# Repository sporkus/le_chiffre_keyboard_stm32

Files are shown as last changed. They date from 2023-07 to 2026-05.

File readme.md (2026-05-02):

# Le Chiffre Keyboard - STM32 version
-----------

Open sourced PCB originally design by tominabox1 updated to STM32 MCU.

## Design goals
* Drop-in replacement to existing cases
* MCU: STM32F072CBT6 (128Kb flash, built-in DFU bootloader) to allow more firmware features
* MX hotswap, Alps support
* Optional 36 key support

## Firmware
* [QMK and vial source](./firmware)
* [zmk config](https://github.com/petejohanson/le-chiffre-stm32-zmk-config)
* [pre-compiled vial](./firmware/le_chiffre_32_vial.bin)

To flash initially using dfu-util or qmk toolbox, plug in the board or push the reset button while DFU button is held down.

## Fabrication
* verified production files can be found [here](./pcb_production)
* pcb dimensions: 84.96x227.34mm
* SK6812 mini 3535 has placement marker on "Data In" pin. Don't confuse it with sk6812-HS mini or sk6812 mini-E.

## Misc
#### 3D assembly preview
* [online viewer](https://3dviewer.net/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)
* [step assembly](./documentation/stm32_hotswap_chiffre-3D.step)

#### PCB renders
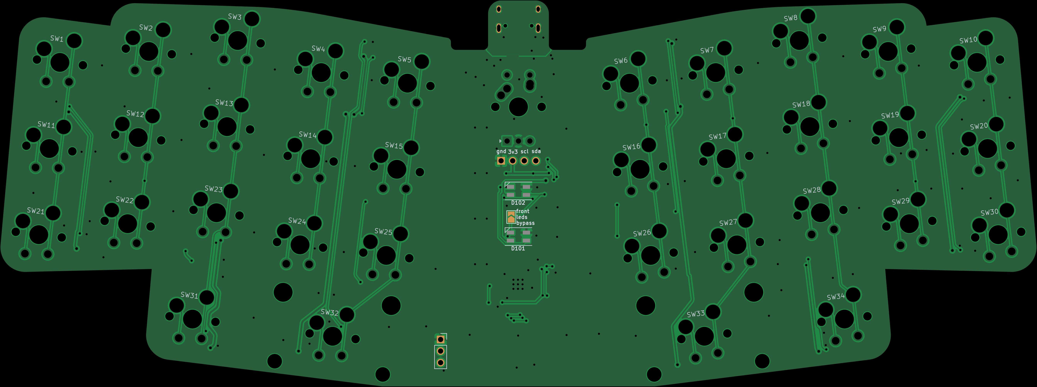
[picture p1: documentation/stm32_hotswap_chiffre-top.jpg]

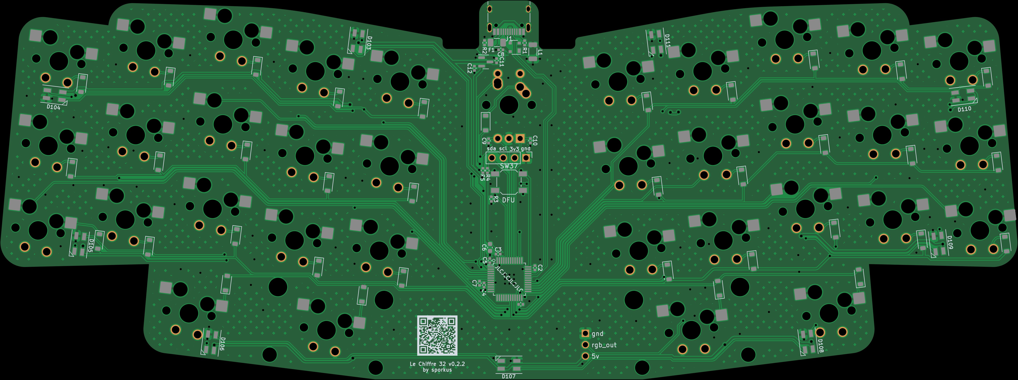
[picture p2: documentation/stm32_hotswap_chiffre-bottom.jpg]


#### BoM
[interactive BoM](./documentation/stm32_hotswap_chiffre-ibom.html)

#### Schematic
[Schematic pdf](./documentation/stm32_hotswap_chiffre-schematic.pdf)

#### Case
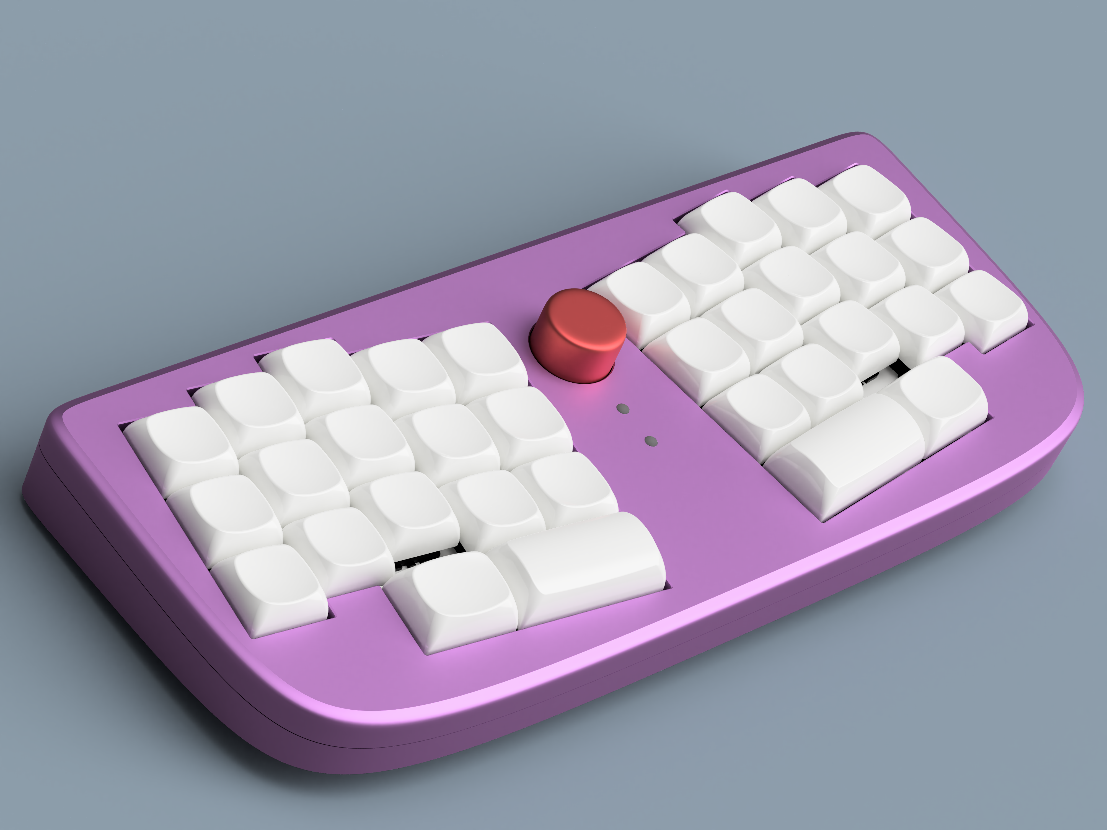
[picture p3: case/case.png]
3d printable case


## Credits
tominabox1 for the [original design](https://github.com/tominabox1/Le-Chiffre-Keyboard)

## Changelog
* v0.3.0: add optional 36 key support
* v0.2.2: change center switch to soldered instead of hotswap. Group buy.
* v0.2.1: added front led bypass jumper
* v0.2.0: improved protection circuit
* v0.1: working initial prototypes

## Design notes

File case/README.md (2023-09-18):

# 3d printable case
---

- 4-degree top mount case.
- Two versions of case top provided in stl:
    - 19mm knob + 2.5 diameter lightpipes
    - plain top with no cutouts

### Hardware
- 15x: m2 x 3mm x 3mm heatset insert
- 15x: m2 x 6mm or 8mm screws (depend on o-rings used)
- 0 - 23x: 2mm ID x 2mm height x 6mm diameter orings
- 2x: 2.5mm diameter x 11mm lightpipes (can be cut down from longer)
- 4x: [SKUF](https://github.com/Zambumon/SKUF)


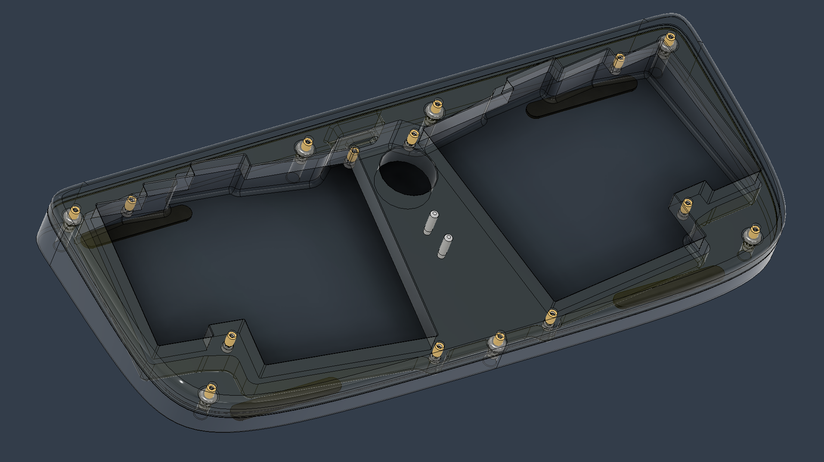
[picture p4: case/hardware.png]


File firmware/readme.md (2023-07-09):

# Le Chiffre 32

32-bit version of the Le Chiffre originally designed by tominabox1

* Keyboard Maintainer: [sporkus](https://github.com/sporkus)
* Hardware Supported: APM32F072
* Hardware Availability: [](https://github.com/sporkus/le_chiffre_keyboard_stm32)

Make example for this keyboard (after setting up your build environment):

    qmk compile -kb sporkus/le_chiffre_stm32 -km default

Flashing example for this keyboard:

    qmk flash -kb sporkus/le_chiffre_stm32 -km default

See the [build environment setup](https://docs.qmk.fm/#/getting_started_build_tools) and the [make instructions](https://docs.qmk.fm/#/getting_started_make_guide) for more information. Brand new to QMK? Start with our [Complete Newbs Guide](https://docs.qmk.fm/#/newbs).

## Bootloader

Enter the DFU bootloader in 3 ways:

* **Physical DFU button**: hold the button while powering up the keyboard
* **Keycode in layout**: Press the key mapped to `QK_BOOT` if it is available

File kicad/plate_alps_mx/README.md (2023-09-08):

# Mixed Alps/MX plate

All cutouts are for Alps except MX cutouts in the 2u keys

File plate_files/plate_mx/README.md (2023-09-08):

# MX Plate

* one piece version based on https://github.com/tominabox1/Le-Chiffre-Keyboard/tree/master/KiCad/Le%20Chiffre%20v2/LeChiffre_Plate

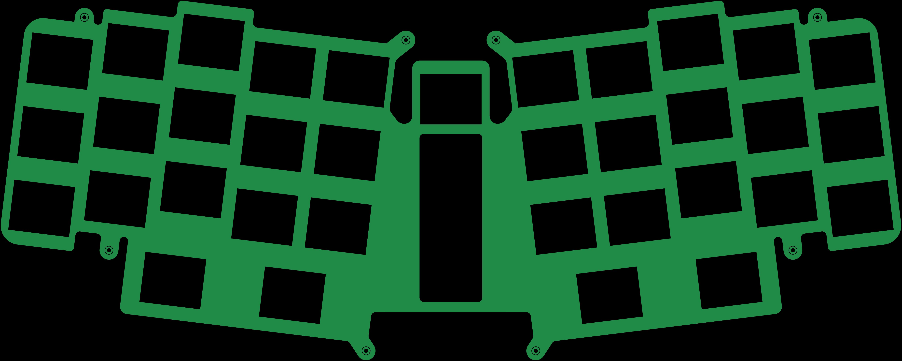
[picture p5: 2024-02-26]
plate_files/plate_alps/plate_alps-top.jpg

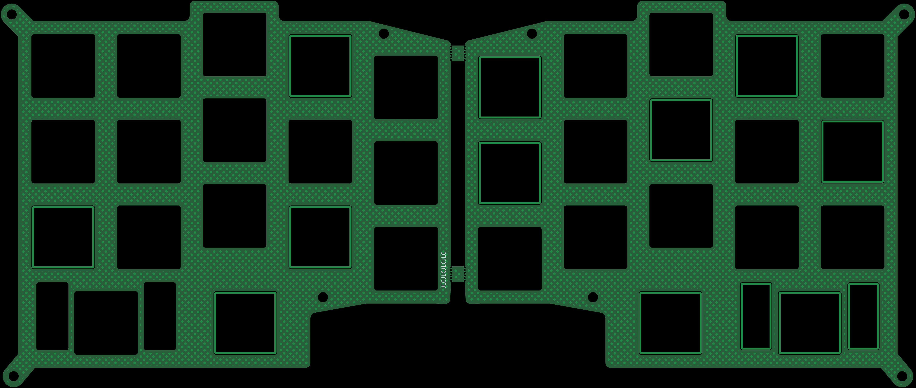
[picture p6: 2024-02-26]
plate_files/plate_mx/LeChiffre_Plate-top.jpg

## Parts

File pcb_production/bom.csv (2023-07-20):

Designator | Footprint | Quantity | Value | LCSC Part #
C1, C10, C2, C3, C4, C5, C7, C8, C9 | 0402 | 9 | 100nF | C307331
C11, C12 | 0402 | 2 | 1uF | C52923
C6 | 0603 | 1 | 10uF
D1, D10, D11, D12, D13, D14, D15, D16, D17, D18, D19, D2, D20, D21, D22, D23, D24, D25, D26, D27, D28, D29, D3, D30, D31, D32, D33, D34, D35, D4, D5, D6, D7, D8, D9 | D_SOD-123 | 35 | 1N4148W
D101, D102, D103, D104, D105, D106, D107, D108, D109, D110, D111 | LED_SK6812MINI_PLCC4_3.5x3.5mm_P1.75mm | 11 | SK6812MINI
F1 | 1206 | 1 | ASMD1206-150 | C135341
J1 | USB_C_Receptacle_HRO_TYPE-C-31-M-12 | 1 | USB_C_Receptacle_USB2.0
J101 | PinSocket_1x03_P2.54mm_Vertical | 1 | Conn_01x03_Female
JP2 | SolderJumper-2_P1.3mm_Open_TrianglePad1.0x1.5mm | 1 | Jumper_2_Open
L1 | 1206 | 1 | 60R@100MHz | C33600
R1, R2 | 0402 | 2 | 5.1k
R3 | 0402 | 1 | 10k
R4, R5 | 0402 | 2 | 4.7k
SW1, SW10, SW11, SW12, SW13, SW14, SW15, SW16, SW17, SW18, SW19, SW2, SW20, SW21, SW22, SW23, SW24, SW25, SW26, SW27, SW28, SW29, SW3, SW30, SW4, SW5, SW6, SW7, SW8, SW9 | MX-Hotswap-Alps-1U | 30 | SW_Push
SW31, SW34 | MX-Hotswap-Alps-1.25U | 2 | SW_Push
SW32, SW33 | MX-Hotswap-Alps-2U | 2 | SW_Push
SW35 | MX-Alps-Hybrid-1U | 1 | SW_Push
SW37 | SW_SPST_SKQG_WithoutStem | 1 | SKQGABE010 | C115351
U1 | LQFP-48_7x7mm_P0.5mm | 1 | STM32F072CBT6
U2 | SOT-143 | 1 | PRTR5V0U2X | C2827688
U3 | SOT-23 | 1 | XC6206PxxxMR-Regulator_Linear | C5446

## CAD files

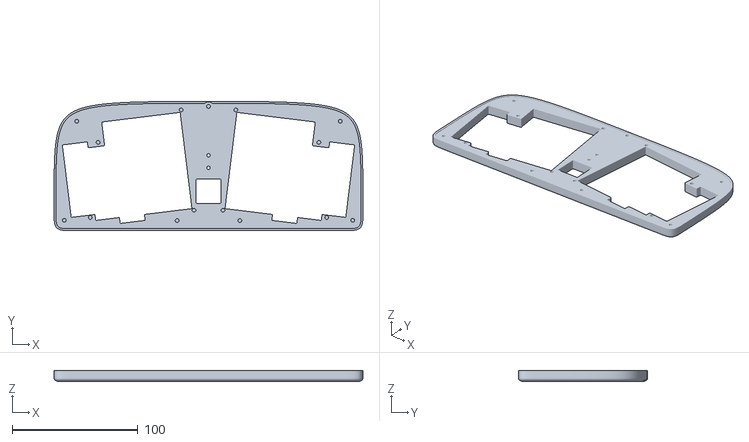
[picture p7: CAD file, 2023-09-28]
case/top_switch_cutout.stl
246.0 x 102.9 x 8.65

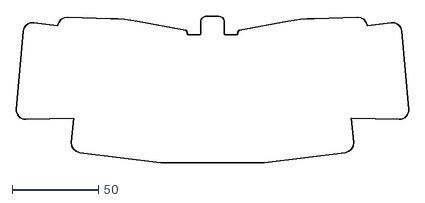
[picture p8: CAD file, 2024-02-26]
documentation/34key/stm32_hotswap_chiffre-Edge_Cuts.dxf
227.6 x 84.9

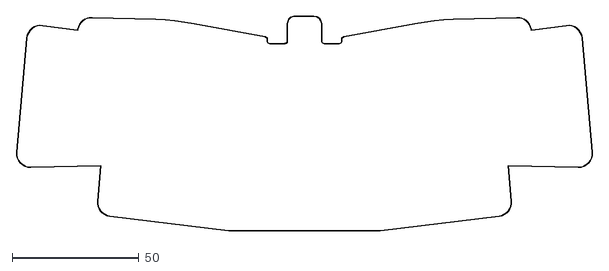
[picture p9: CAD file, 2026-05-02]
documentation/36key/stm32_chiffre_36keys-Edge_Cuts.dxf
227.6 x 84.9

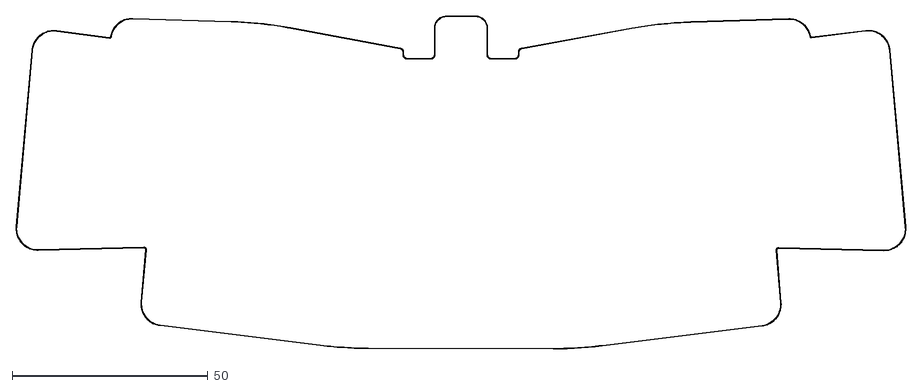
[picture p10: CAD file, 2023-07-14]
kicad/pcb/stm32_hotswap_chiffre-Edge_Cuts.dxf
227.4 x 85.0

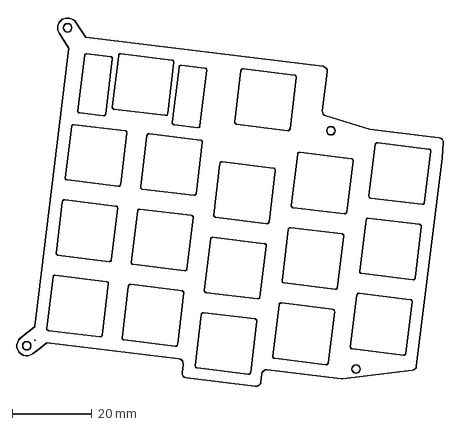
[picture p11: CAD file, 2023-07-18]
kicad/plate/Plate 5.14.32 PM.dxf
107.2 x 92.9 mm

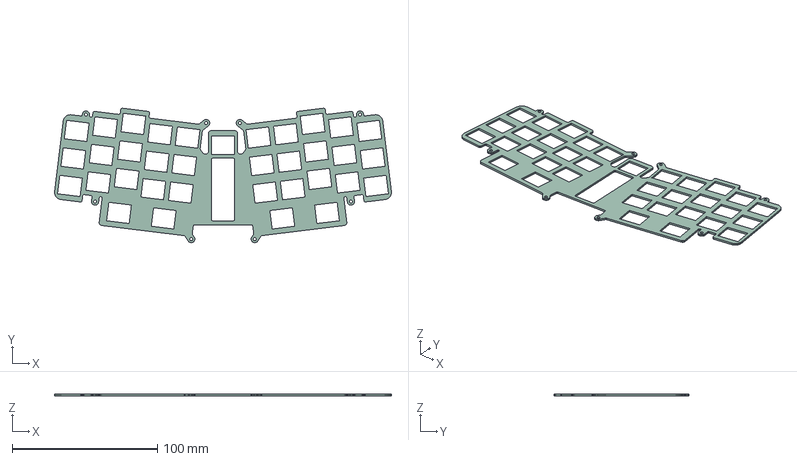
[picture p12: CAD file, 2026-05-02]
plate_files/plate_alps/plate_alps-3D.step
231.6 x 92.5 x 1.20 mm

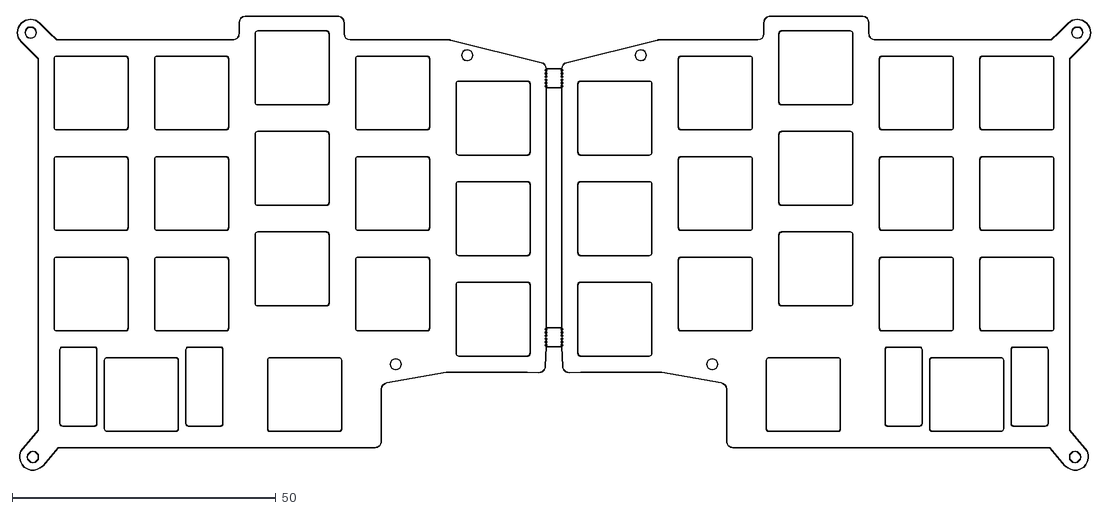
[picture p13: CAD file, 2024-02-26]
plate_files/plate_mx/LeChiffre_Plate-Edge_Cuts.dxf
203.9 x 86.2

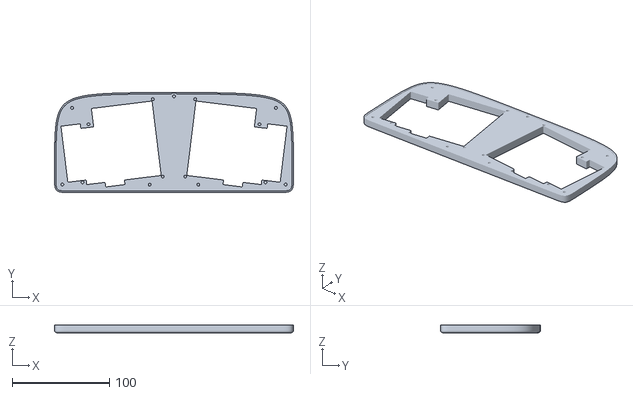
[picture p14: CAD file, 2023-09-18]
case/top_plain.stl
246.0 x 102.9 x 8.65

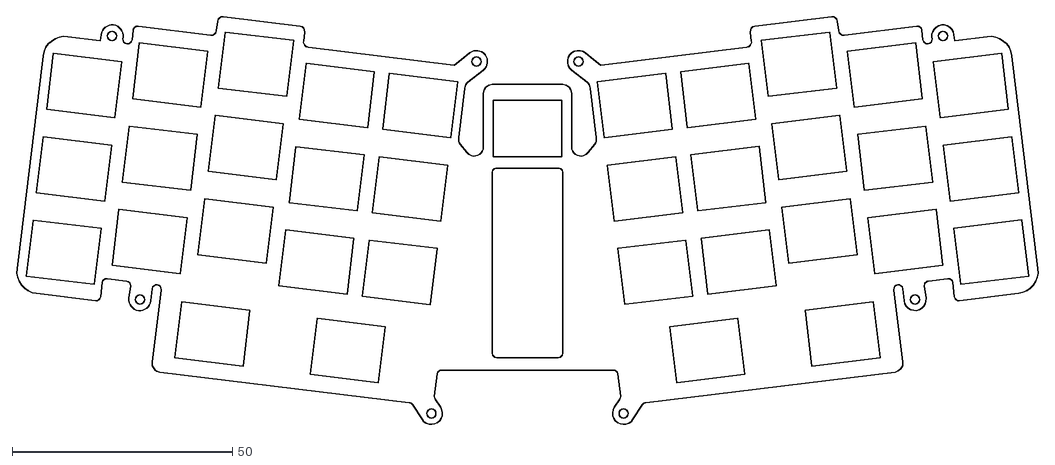
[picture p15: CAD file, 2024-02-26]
plate_files/plate_alps/plate_alps-Edge_Cuts.dxf
231.9 x 92.6

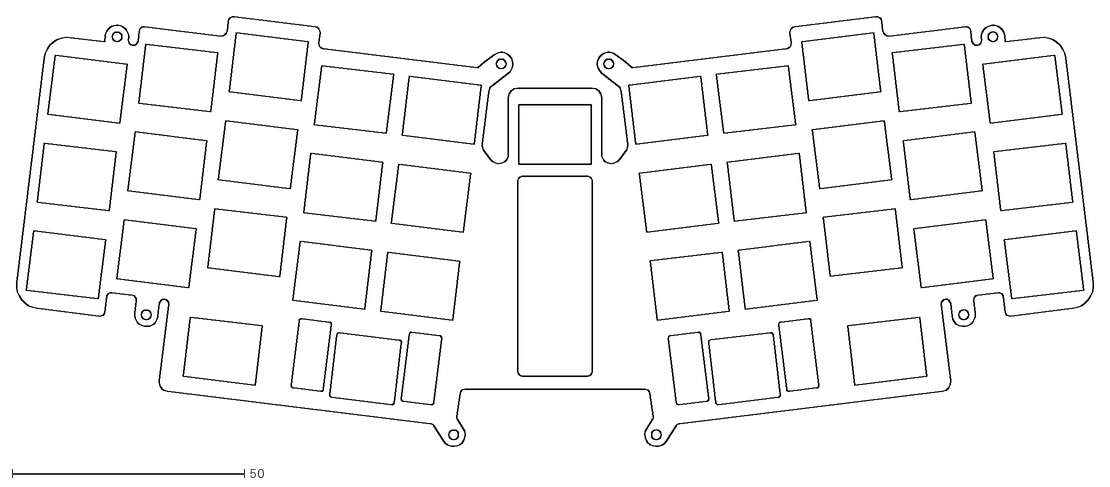
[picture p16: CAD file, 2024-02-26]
plate_files/plate_alps_mx/plate_alps_mx-Edge_Cuts.dxf
231.9 x 92.6

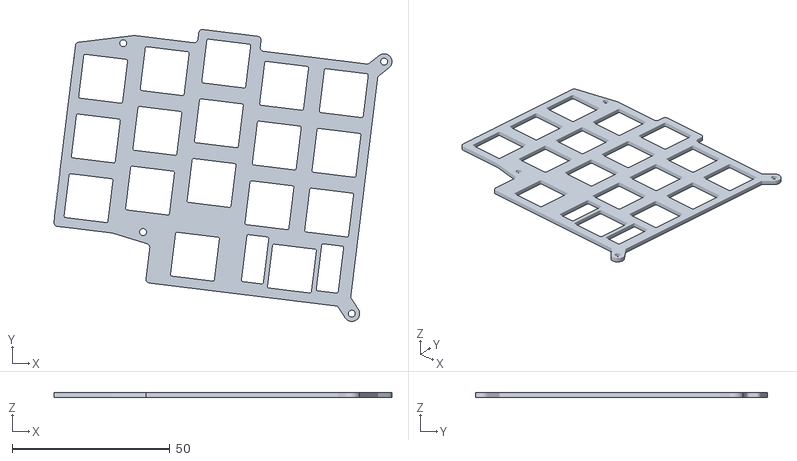
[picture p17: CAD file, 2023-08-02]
case/plate.stl
107.1 x 92.5 x 1.60

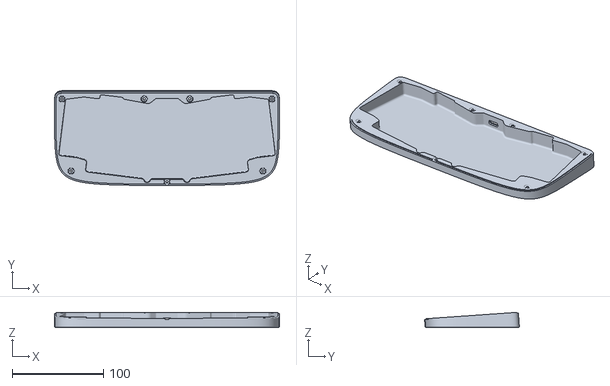
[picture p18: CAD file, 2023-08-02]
case/bottom.stl
246.0 x 103.7 x 16.7

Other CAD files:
plate_files/plate_alps_mx/plate_alps_mx-3D.step
case/top.stl

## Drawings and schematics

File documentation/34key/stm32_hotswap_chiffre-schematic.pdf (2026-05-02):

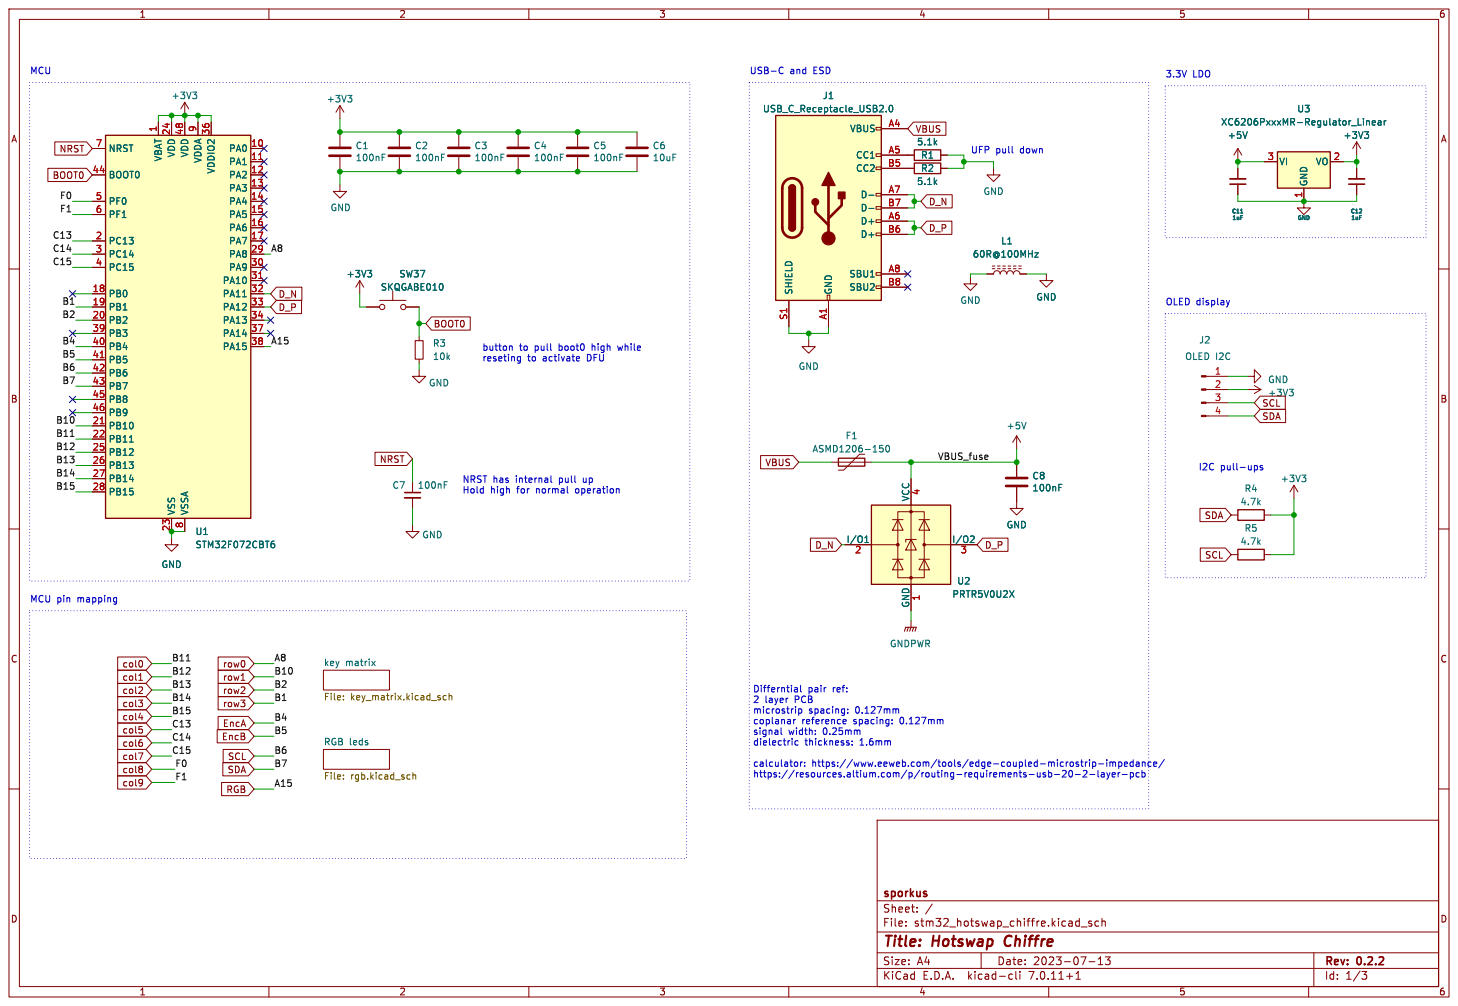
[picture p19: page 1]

3.3V LDO MCU pin mapping

1 PA0 10 PA1 11 PA2 12 PA3 13 PA4 14 PA5 15 PA6 16 PA7 17 PB0 18 PB1 19 PC13 2 PB2 20 PB10 21 PB11 22 VSS 23 VDD 24 PB12 25 PB13 26 PB14 27 PB15 28 PA8 29 PC14 3 PA9 30 PA10 31 PA11 32 PA12 33 PA13 34 VDDIO2 36 PA14 37 PA15 38 PB3 39 PC15 4 PB4 40 PB5 41 PB6 42 PB7 43 BOOT0 44 PB8 45 PB9 46 VDD 48 PF0 5 PF1 6 NRST 7 VSSA

button to pull boot0 high while

File: stm32_hotswap_chiffre.kicad_sch Sheet: / sporkus RGB leds File: rgb.kicad_sch

https://resources.altium.com/p/routing-requirements-usb-20-2-layer-pcb

Id: 1/3 Title: Hotswap Chiffre

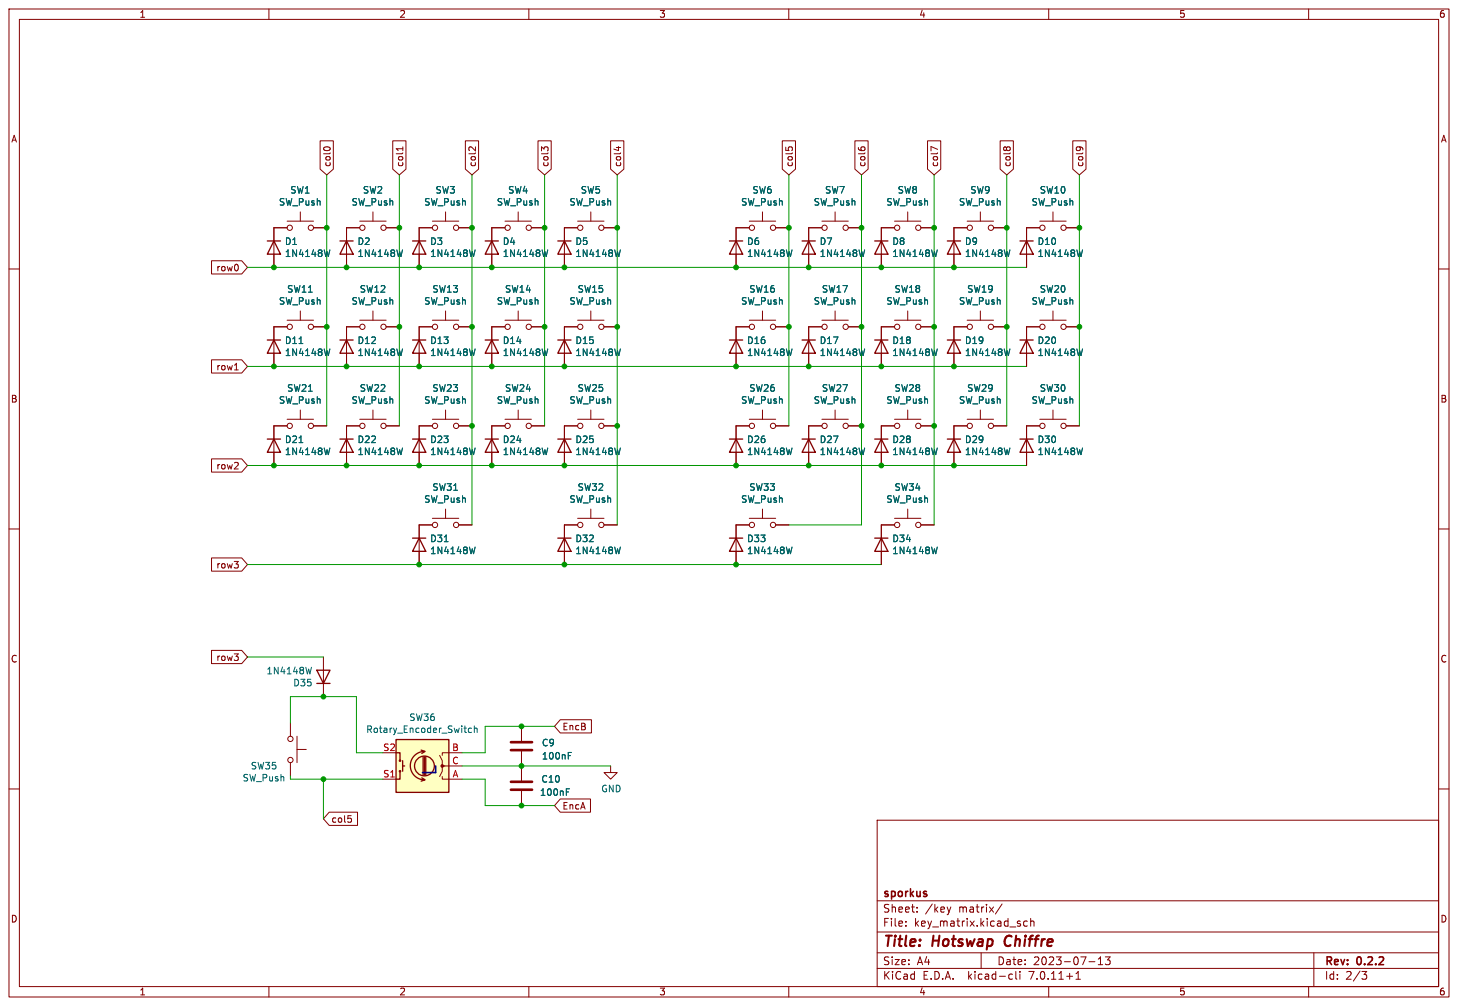
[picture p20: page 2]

File: key_matrix.kicad_sch Sheet: /key matrix/ sporkus SW33 SW_Push D25

Id: 2/3 Title: Hotswap Chiffre

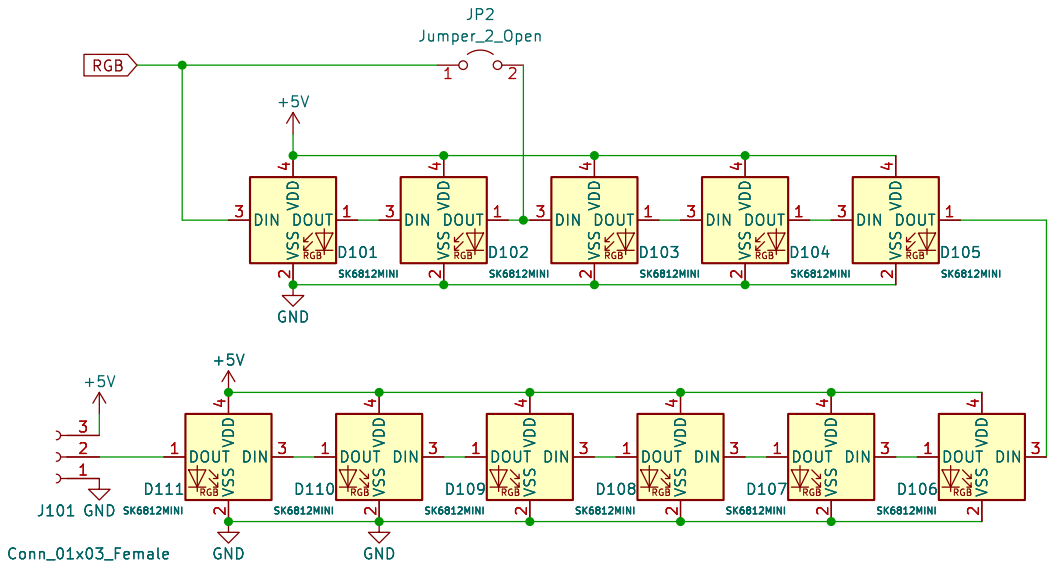
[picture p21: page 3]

Id: 3/3 Title: Hotswap Chiffre

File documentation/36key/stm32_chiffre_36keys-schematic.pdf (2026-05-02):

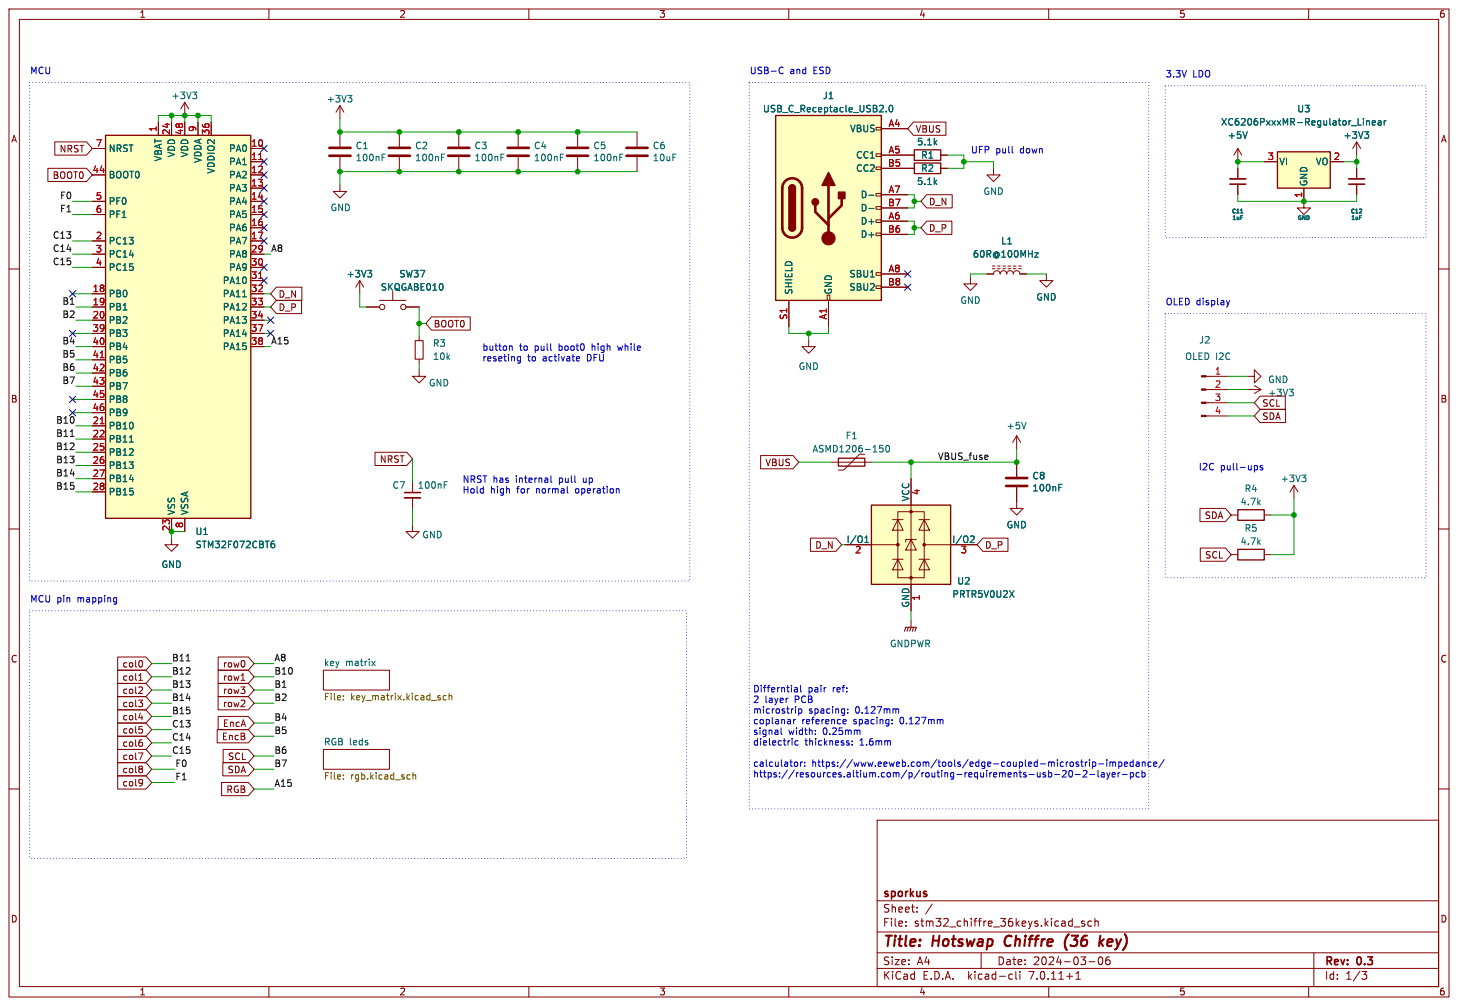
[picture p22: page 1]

1 PA0 10 PA1 11 PA2 12 PA3 13 PA4 14 PA5 15 PA6 16 PA7 17 PB0 18 PB1 19 PC13 2 PB2 20 PB10 21 PB11 22 VSS 23 VDD 24 PB12 25 PB13 26 PB14 27 PB15 28 PA8 29 PC14 3 PA9 30 PA10 31 PA11 32 PA12 33 PA13 34 VDDIO2 36 PA14 37 PA15 38 PB3 39 PC15 4 PB4 40 PB5 41 PB6 42 PB7 43 BOOT0 44 PB8 45 PB9 46 VDD 48 PF0 5 PF1 6 NRST 7 VSSA

button to pull boot0 high while

Id: 1/3 Title: Hotswap Chiffre (36 key) File: stm32_chiffre_36keys.kicad_sch Sheet: / sporkus RGB leds File: rgb.kicad_sch

https://resources.altium.com/p/routing-requirements-usb-20-2-layer-pcb

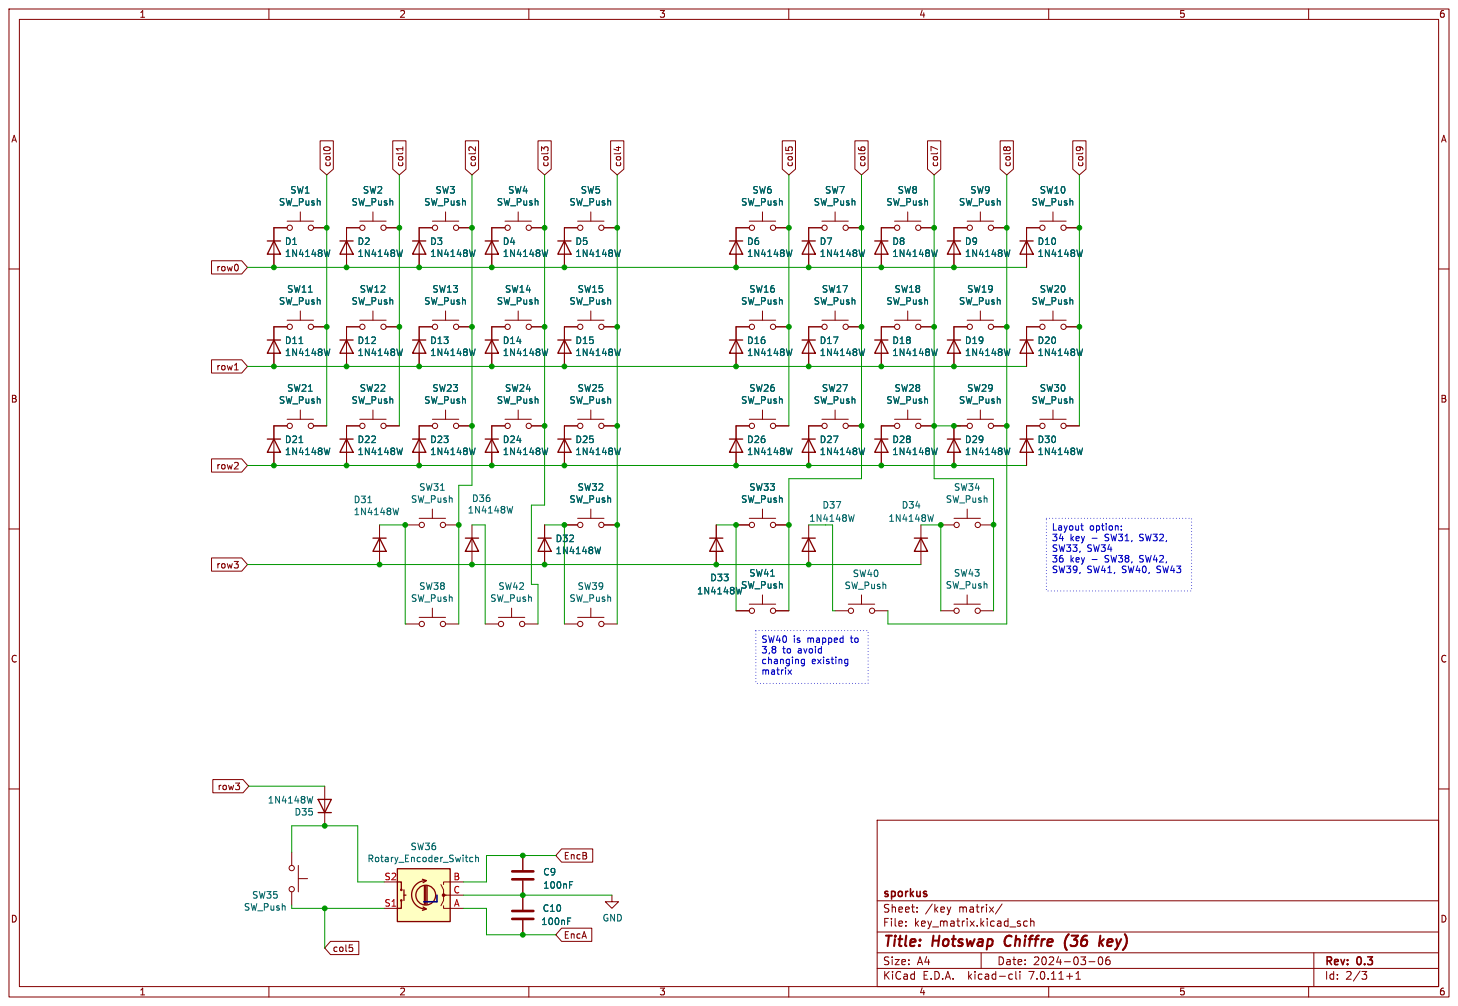
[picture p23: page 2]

Id: 2/3 Title: Hotswap Chiffre (36 key) File: key_matrix.kicad_sch Sheet: /key matrix/ sporkus SW32 SW_Push D5


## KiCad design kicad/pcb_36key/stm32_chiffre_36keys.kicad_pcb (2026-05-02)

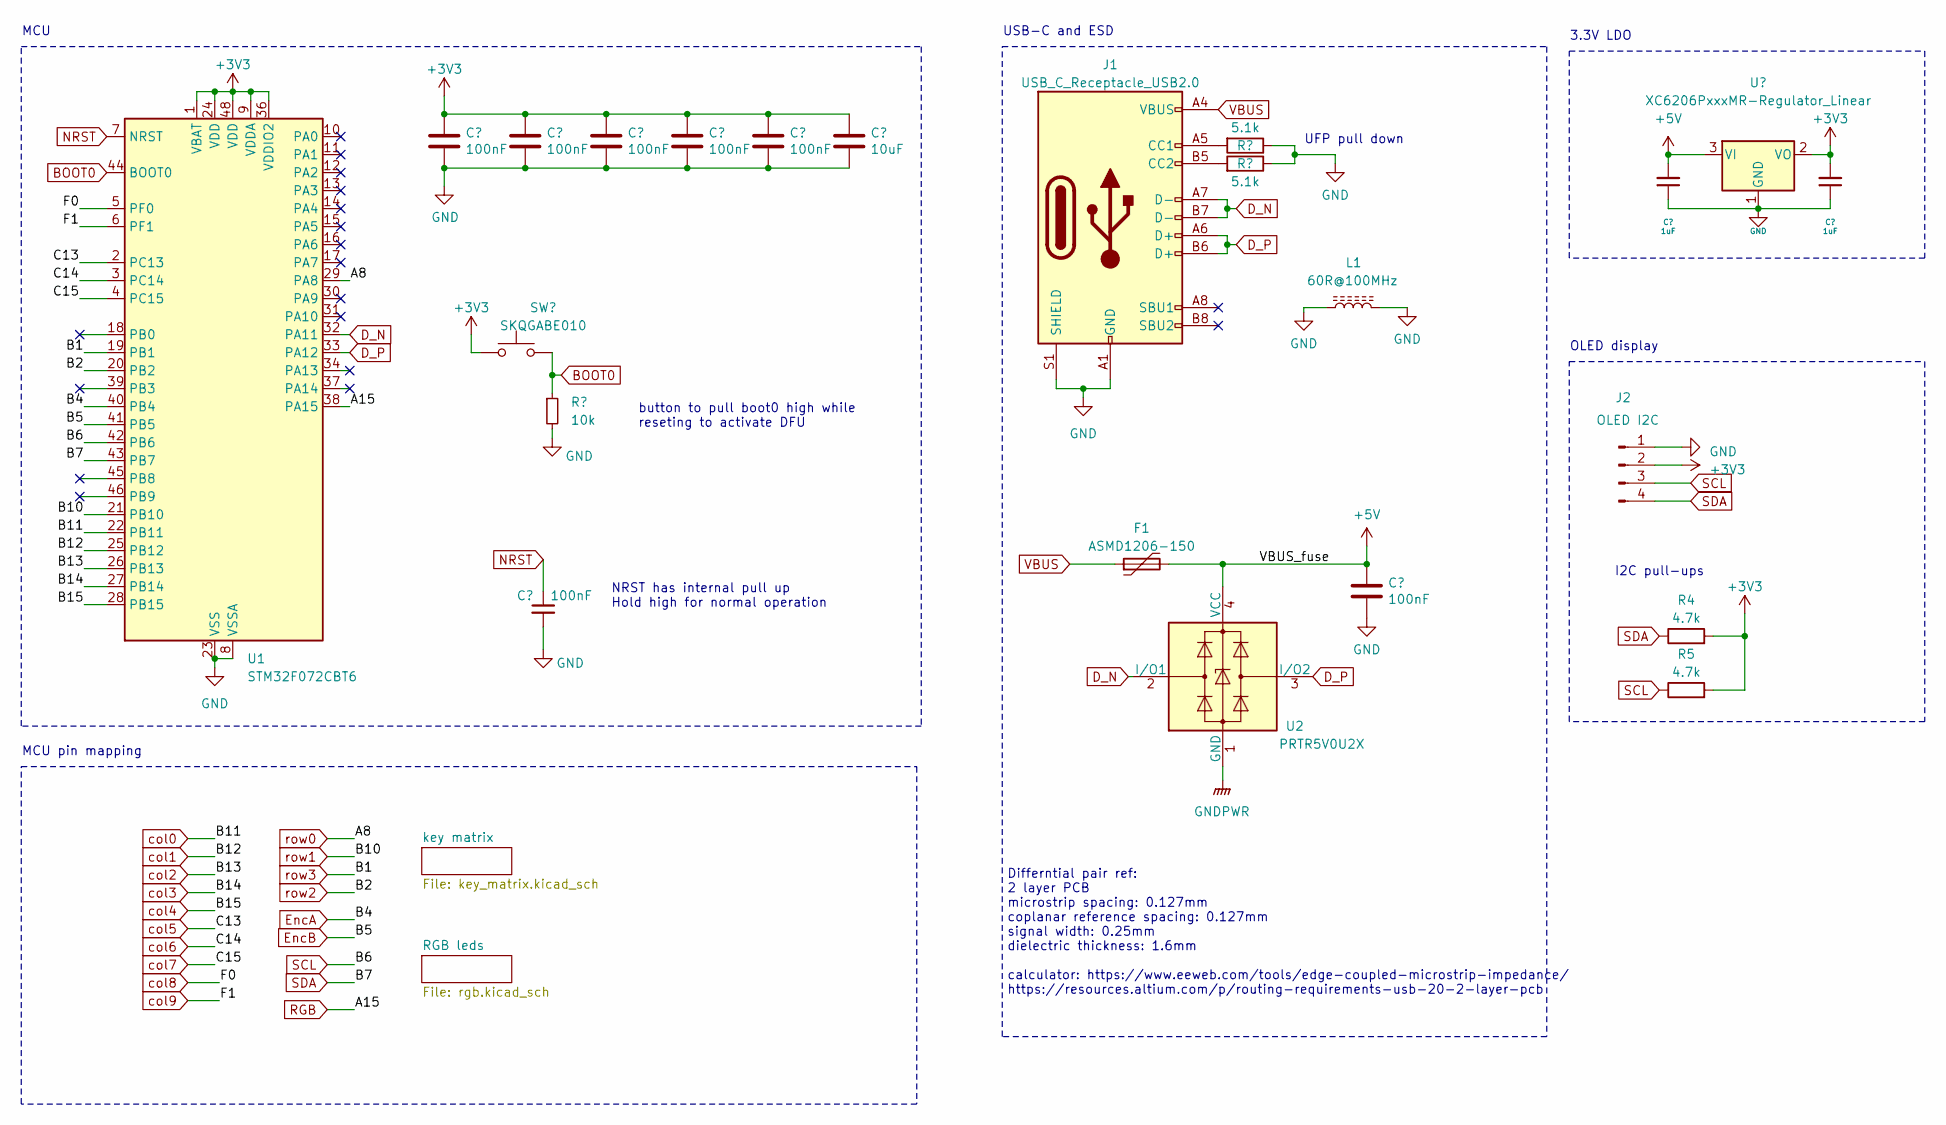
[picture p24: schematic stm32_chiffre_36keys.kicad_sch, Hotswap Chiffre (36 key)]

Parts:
C1, C2, C3, C4, C5, C7, C8: 100nF; C_0402_1005Metric; LCSC C307331
C6: 10uF; C_0603_1608Metric
C11, C12: 1uF; C_0402_1005Metric; LCSC C52923
F1: ASMD1206-150; Fuse_1206_3216Metric; LCSC C135341
J1: USB_C_Receptacle_USB2.0; USB_C_Receptacle_HRO_TYPE-C-31-M-12; JlcRotOffset 180
J2: OLED I2C; PinHeader_1x04_P2.54mm_Vertical
L1: 60R@100MHz; L_1206_3216Metric; Manufacturer Part No MLB3216-600P4A(f); LCSC C33600
R1, R2: 5.1k; R_0402_1005Metric
R3: 10k; R_0402_1005Metric
R4, R5: 4.7k; R_0402_1005Metric
SW37: SKQGABE010; SW_SPST_SKQG_WithoutStem; LCSC C115351
U1: STM32F072CBT6; LQFP-48_7x7mm_P0.5mm; JlcRotOffset 90
U2: PRTR5V0U2X; SOT-143; LCSC C2827688
U3: XC6206PxxxMR-Regulator_Linear; SOT-23; LCSC C5446

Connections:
+3V3: C1.1, C2.1, C3.1, C4.1, C5.1, C6.1, C12.2, J2.2, R4.2, R5.2, SW37.1, U1.1 (VBAT), U1.9 (VDDA), U1.24 (VDD), U1.36 (VDDIO2), U1.48 (VDD), U3.2 (VO)
+5V: C8.1, C11.2, F1.2, U2.4 (VCC), U3.3 (VI); also elsewhere on the board
BOOT0: R3.1, SW37.2, U1.44 (BOOT0)
D_N: J1.A7 (D-), J1.B7 (D-), U1.32 (PA11), U2.2 (I/O1)
D_P: J1.A6 (D+), J1.B6 (D+), U1.33 (PA12), U2.3 (I/O2)
EncA: U1.40 (PB4); also elsewhere on the board
EncB: U1.41 (PB5); also elsewhere on the board
GND: C1.2, C2.2, C3.2, C4.2, C5.2, C6.2, C7.2, C8.2, C11.1, C12.1, J1.A1 (GND), J1.A12 (GND), J1.B1 (GND), J1.B12 (GND), J1.S1 (SHIELD), J2.1, L1.1, L1.2, R1.1, R2.1, R3.2, U1.8 (VSSA), U1.23 (VSS), U1.35 (VSS), U1.47 (VSS), U3.1 (GND); also elsewhere on the board
GNDPWR: U2.1 (GND)
NRST: C7.1, U1.7 (NRST)
unnamed: J1.A5 (CC1), R1.2
unnamed: J1.B5 (CC2), R2.2
RGB: U1.38 (PA15); also elsewhere on the board
SCL: J2.3, R5.1, U1.42 (PB6)
SDA: J2.4, R4.1, U1.43 (PB7)
VBUS: F1.1, J1.A4 (VBUS), J1.A9 (VBUS), J1.B4 (VBUS), J1.B9 (VBUS)
col0: U1.22 (PB11); also elsewhere on the board
col1: U1.25 (PB12); also elsewhere on the board
col2: U1.26 (PB13); also elsewhere on the board
col3: U1.27 (PB14); also elsewhere on the board
col4: U1.28 (PB15); also elsewhere on the board
col5: U1.2 (PC13); also elsewhere on the board
col6: U1.3 (PC14); also elsewhere on the board
col7: U1.4 (PC15); also elsewhere on the board
col8: U1.5 (PF0); also elsewhere on the board
col9: U1.6 (PF1); also elsewhere on the board
row0: U1.29 (PA8); also elsewhere on the board
row1: U1.21 (PB10); also elsewhere on the board
row2: U1.20 (PB2); also elsewhere on the board
row3: U1.19 (PB1); also elsewhere on the board

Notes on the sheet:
button to pull boot0 high while reseting to activate DFU
I2C pull-ups
UFP pull down
MCU pin mapping
MCU
3.3V LDO
USB-C and ESD
OLED display
NRST has internal pull up Hold high for normal operation
Differntial pair ref: 2 layer PCB microstrip spacing: 0.127mm coplanar reference spacing: 0.127mm signal width: 0.25mm dielectric thickness: 1.6mm calculator: https://www.eeweb.com/tools/edge-coupled-microstrip-impedance/ https://resources.altium.com/p/routing-requirements-usb-20-2-layer-pcb

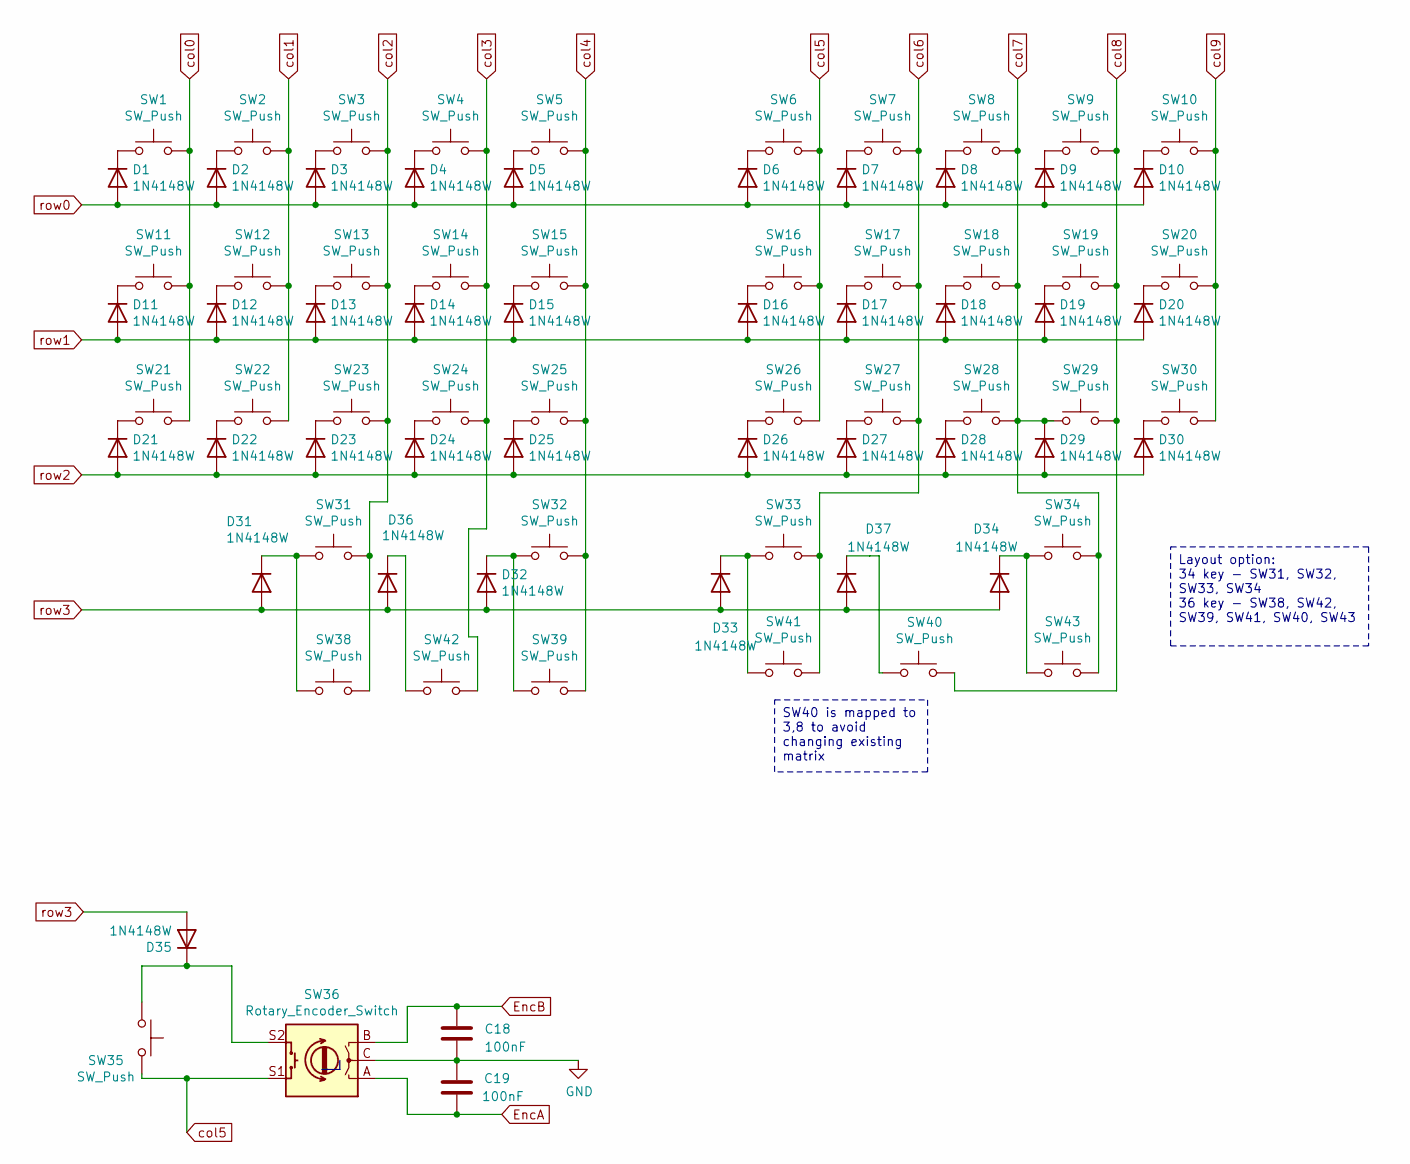
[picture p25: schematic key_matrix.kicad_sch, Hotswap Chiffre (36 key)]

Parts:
C18, C19: 100nF; C_0402_1005Metric; LCSC C307331
D1, D2, D3, D4, D5, D11, D12, D13, D14, D15, D21, D22, D23, D24, D25, D31, D32, D36: 1N4148W; D_SOD-123; JlcRotOffset 14
D6, D7, D8, D9, D10, D16, D17, D18, D19, D20, D26, D27, D28, D29, D30, D33, D34, D37: 1N4148W; D_SOD-123; JlcRotOffset -14
D35: 1N4148W; D_SOD-123; JlcRotOffset 0
SW1, SW2, SW3, SW4, SW5, SW6, SW7, SW8, SW9, SW10, SW11, SW12, SW13, SW14, SW15, SW16, SW17, SW18, SW19, SW20, SW21, SW22, SW23, SW24, SW25, SW26, SW27, SW28, SW29, SW30, SW38, SW40, SW41, SW42: SW_Push; MX-Hotswap-Alps-1U
SW31, SW34, SW39, SW43: SW_Push; MX-Hotswap-Alps-1.25U
SW32, SW33: SW_Push; MX-Hotswap-Alps-2U
SW35: SW_Push; MX-Alps-Hybrid-1U
SW36: Rotary_Encoder_Switch; RotaryEncoder_EC11_no_mp

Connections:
EncA: SW36.A; also elsewhere on the board
EncB: SW36.B; also elsewhere on the board
GND: SW36.C; also elsewhere on the board
unnamed: D1.1 (K), SW1.1
unnamed: D2.1 (K), SW2.1
unnamed: D3.1 (K), SW3.1
unnamed: D4.1 (K), SW4.1
unnamed: D5.1 (K), SW5.1
unnamed: D6.1 (K), SW6.1
unnamed: D7.1 (K), SW7.1
unnamed: D8.1 (K), SW8.1
unnamed: D9.1 (K), SW9.1
unnamed: D10.1 (K), SW10.1
unnamed: D11.1 (K), SW11.1
unnamed: D12.1 (K), SW12.1
unnamed: D13.1 (K), SW13.1
unnamed: D14.1 (K), SW14.1
unnamed: D15.1 (K), SW15.1
unnamed: D16.1 (K), SW16.1
unnamed: D17.1 (K), SW17.1
unnamed: D18.1 (K), SW18.1
unnamed: D19.1 (K), SW19.1
unnamed: D20.1 (K), SW20.1
unnamed: D21.1 (K), SW21.1
unnamed: D22.1 (K), SW22.1
unnamed: D23.1 (K), SW23.1
unnamed: D24.1 (K), SW24.1
unnamed: D25.1 (K), SW25.1
unnamed: D26.1 (K), SW26.1
unnamed: D27.1 (K), SW27.1
unnamed: D28.1 (K), SW28.1
unnamed: D30.1 (K), SW30.1
unnamed: D31.1 (K), SW31.1, SW38.2
unnamed: D32.1 (K), SW32.1, SW39.2
unnamed: D33.1 (K), SW33.1, SW41.2
unnamed: D34.1 (K), SW34.2, SW43.1
unnamed: D35.1 (K), SW35.1, SW36.S2
unnamed: D36.1 (K), SW42.1
unnamed: D37.1 (K), SW40.1
col0: SW1.2, SW11.2, SW21.2; also elsewhere on the board
col1: SW2.2, SW12.2, SW22.2; also elsewhere on the board
col2: SW3.2, SW13.2, SW23.2, SW31.2, SW38.1; also elsewhere on the board
col3: SW4.2, SW14.2, SW24.2, SW42.2; also elsewhere on the board
col4: SW5.2, SW15.2, SW25.2, SW32.2, SW39.1; also elsewhere on the board
col5: SW6.2, SW16.2, SW26.2, SW35.2, SW36.S1; also elsewhere on the board
col6: SW7.2, SW17.2, SW27.2, SW33.2, SW41.1; also elsewhere on the board
col7: D29.1 (K), SW8.2, SW18.2, SW28.2, SW29.1, SW34.1, SW43.2; also elsewhere on the board
col8: SW9.2, SW19.2, SW29.2, SW40.2; also elsewhere on the board
col9: SW10.2, SW20.2, SW30.2; also elsewhere on the board
row0: D1.2 (A), D2.2 (A), D3.2 (A), D4.2 (A), D5.2 (A), D6.2 (A), D7.2 (A), D8.2 (A), D9.2 (A), D10.2 (A); also elsewhere on the board
row1: D11.2 (A), D12.2 (A), D13.2 (A), D14.2 (A), D15.2 (A), D16.2 (A), D17.2 (A), D18.2 (A), D19.2 (A), D20.2 (A); also elsewhere on the board
row2: D21.2 (A), D22.2 (A), D23.2 (A), D24.2 (A), D25.2 (A), D26.2 (A), D27.2 (A), D28.2 (A), D29.2 (A), D30.2 (A); also elsewhere on the board
row3: D31.2 (A), D32.2 (A), D33.2 (A), D34.2 (A), D35.2 (A), D36.2 (A), D37.2 (A); also elsewhere on the board

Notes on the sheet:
SW40 is mapped to 3,8 to avoid changing existing matrix
Layout option: 34 key - SW31, SW32, SW33, SW34 36 key - SW38, SW42, SW39, SW41, SW40, SW43

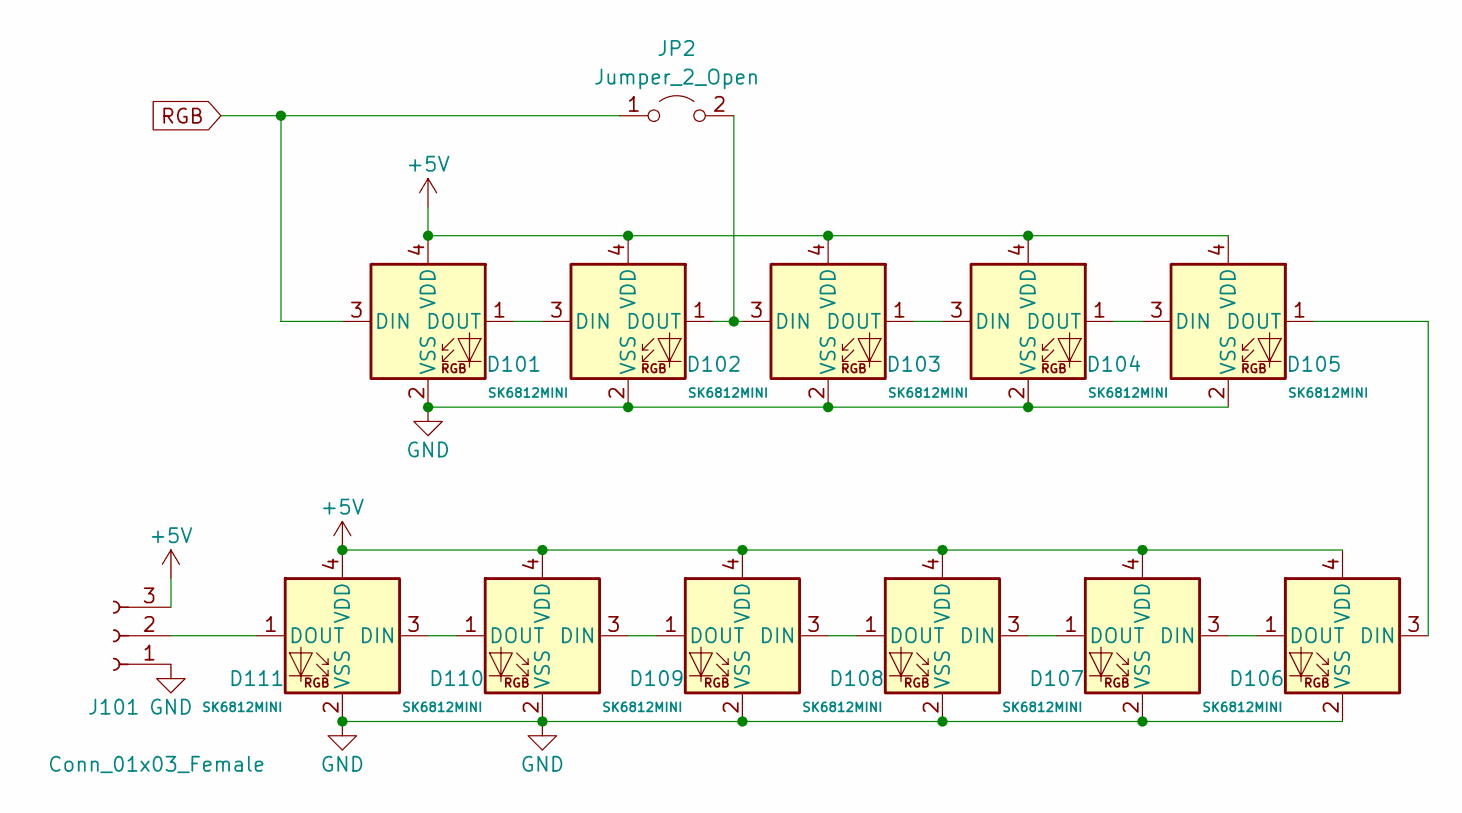
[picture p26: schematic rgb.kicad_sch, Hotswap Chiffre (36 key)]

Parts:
D101, D102: SK6812MINI; LED_SK6812MINI_PLCC4_3.5x3.5mm_P1.75mm
D103, D105, D106: SK6812MINI; LED_SK6812MINI_PLCC4_3.5x3.5mm_P1.75mm; JlcRotOffset -14
D104: SK6812MINI; LED_SK6812MINI_PLCC4_3.5x3.5mm_P1.75mm; JlcRotOffset 166
D107: SK6812MINI; LED_SK6812MINI_PLCC4_3.5x3.5mm_P1.75mm; JlcRotOffset 180
D108, D109, D111: SK6812MINI; LED_SK6812MINI_PLCC4_3.5x3.5mm_P1.75mm; JlcRotOffset 14
D110: SK6812MINI; LED_SK6812MINI_PLCC4_3.5x3.5mm_P1.75mm; JlcRotOffset 194
J101: Conn_01x03_Female; PinSocket_1x03_P2.54mm_Vertical
JP2: Jumper_2_Open; SolderJumper-2_P1.3mm_Open_TrianglePad1.0x1.5mm

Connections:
+5V: D101.4 (VDD), D102.4 (VDD), D103.4 (VDD), D104.4 (VDD), D105.4 (VDD), D106.4 (VDD), D107.4 (VDD), D108.4 (VDD), D109.4 (VDD), D110.4 (VDD), D111.4 (VDD), J101.3 (Pin_1); also elsewhere on the board
GND: D101.2 (VSS), D102.2 (VSS), D103.2 (VSS), D104.2 (VSS), D105.2 (VSS), D106.2 (VSS), D107.2 (VSS), D108.2 (VSS), D109.2 (VSS), D110.2 (VSS), D111.2 (VSS), J101.1 (Pin_3); also elsewhere on the board
unnamed: D101.1 (DOUT), D102.3 (DIN)
unnamed: D102.1 (DOUT), D103.3 (DIN), JP2.2 (B)
unnamed: D103.1 (DOUT), D104.3 (DIN)
unnamed: D104.1 (DOUT), D105.3 (DIN)
unnamed: D105.1 (DOUT), D106.3 (DIN)
unnamed: D106.1 (DOUT), D107.3 (DIN)
unnamed: D107.1 (DOUT), D108.3 (DIN)
unnamed: D108.1 (DOUT), D109.3 (DIN)
unnamed: D109.1 (DOUT), D110.3 (DIN)
unnamed: D110.1 (DOUT), D111.3 (DIN)
unnamed: D111.1 (DOUT), J101.2
RGB: D101.3 (DIN), JP2.1 (A); also elsewhere on the board

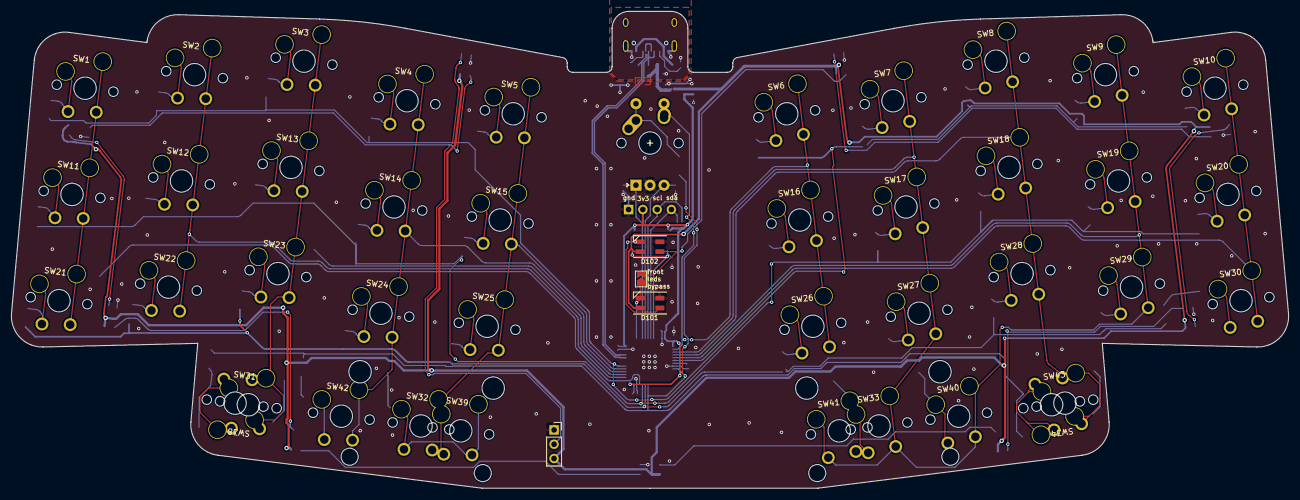
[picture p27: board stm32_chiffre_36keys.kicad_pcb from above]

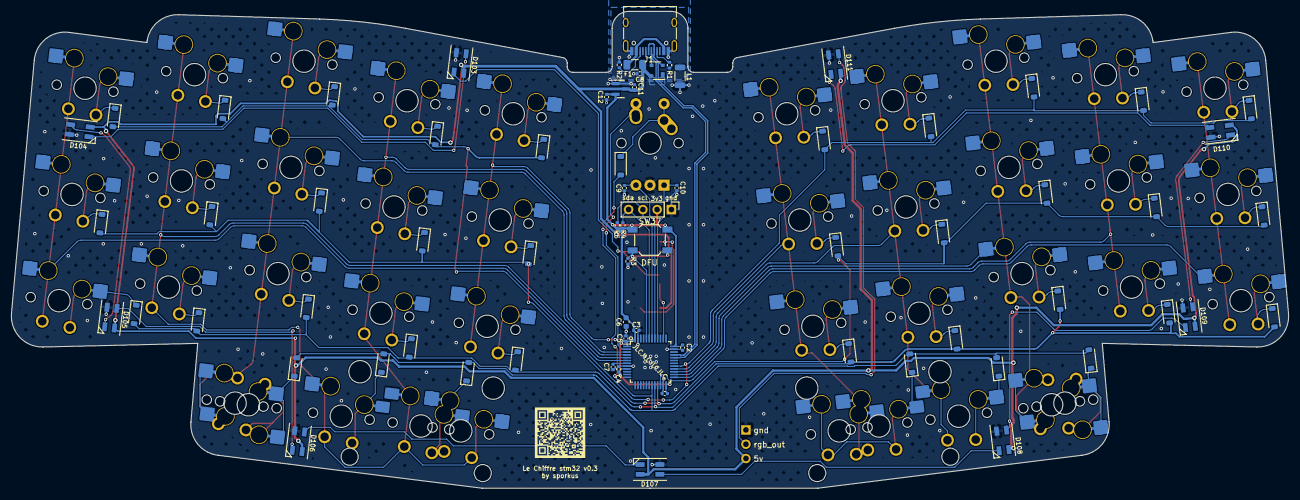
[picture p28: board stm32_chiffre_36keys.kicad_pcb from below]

Board: 2 copper layers, 227.4 x 84.9 mm, 117 parts (71 on the bottom side), 76 nets.

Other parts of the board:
C9, C10: 100nF; C_0402_1005Metric

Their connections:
EncA: C10.1; also elsewhere on the board
EncB: C9.1; also elsewhere on the board
GND: C9.2, C10.2; also elsewhere on the board

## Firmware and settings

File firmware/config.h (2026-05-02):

#pragma once

#define ENCODER_MAP_ENABLE

#define WS2812_DI_PIN A15
#define RGB_MATRIX_LED_COUNT 11
#define DRIVER_LED_TOTAL RGB_MATRIX_LED_COUNT

// Comment these out if you don't want front indicators leds
#define RGB_MODS_INDICATOR_ENABLE
#define RGB_LAYER_INDICATOR_ENABLE

#define RGB_FRONT_BRIGHTNESS_SCALE 3  // Front indicator brightness scaling (0-10)
#define RGB_MATRIX_FRAMEBUFFER_EFFECTS
#define RGB_MATRIX_KEYPRESSES
#define RGB_TRIGGER_ON_KEYDOWN
#define RGB_MATRIX_MAXIMUM_BRIGHTNESS 255
#define RGB_MATRIX_HUE_STEP 8
#define RGB_MATRIX_SAT_STEP 8
#define RGB_MATRIX_VAL_STEP 8
#define RGB_MATRIX_SPD_STEP 16
#define RGB_MATRIX_DEFAULT_MODE RGB_MATRIX_CYCLE_ALL
#define RGB_MATRIX_DEFAULT_HUE 0
#define RGB_MATRIX_DEFAULT_SAT 255
#define RGB_MATRIX_DEFAULT_VAL 100
#define RGB_MATRIX_DEFAULT_SPD 32

// #define ENABLE_RGB_MATRIX_ALPHAS_MODS
// #define ENABLE_RGB_MATRIX_GRADIENT_UP_DOWN
// #define ENABLE_RGB_MATRIX_GRADIENT_LEFT_RIGHT
// #define ENABLE_RGB_MATRIX_BREATHING
// #define ENABLE_RGB_MATRIX_BAND_SAT
// #define ENABLE_RGB_MATRIX_BAND_VAL
// #define ENABLE_RGB_MATRIX_BAND_PINWHEEL_SAT
// #define ENABLE_RGB_MATRIX_BAND_PINWHEEL_VAL
// #define ENABLE_RGB_MATRIX_BAND_SPIRAL_SAT
// #define ENABLE_RGB_MATRIX_BAND_SPIRAL_VAL
#define ENABLE_RGB_MATRIX_CYCLE_ALL
// #define ENABLE_RGB_MATRIX_CYCLE_LEFT_RIGHT
// #define ENABLE_RGB_MATRIX_CYCLE_UP_DOWN
// #define ENABLE_RGB_MATRIX_CYCLE_OUT_IN
// #define ENABLE_RGB_MATRIX_CYCLE_OUT_IN_DUAL
// #define ENABLE_RGB_MATRIX_RAINBOW_MOVING_CHEVRON
// #define ENABLE_RGB_MATRIX_CYCLE_PINWHEEL
// #define ENABLE_RGB_MATRIX_CYCLE_SPIRAL
// #define ENABLE_RGB_MATRIX_DUAL_BEACON
// #define ENABLE_RGB_MATRIX_RAINBOW_BEACON
// #define ENABLE_RGB_MATRIX_RAINBOW_PINWHEELS
// #define ENABLE_RGB_MATRIX_RAINDROPS
// #define ENABLE_RGB_MATRIX_JELLYBEAN_RAINDROPS
// #define ENABLE_RGB_MATRIX_HUE_BREATHING
// #define ENABLE_RGB_MATRIX_HUE_PENDULUM
// #define ENABLE_RGB_MATRIX_HUE_WAVE
// #define ENABLE_RGB_MATRIX_PIXEL_FRACTAL
// #define ENABLE_RGB_MATRIX_PIXEL_FLOW
// #define ENABLE_RGB_MATRIX_PIXEL_RAIN
// #define ENABLE_RGB_MATRIX_TYPING_HEATMAP
// #define ENABLE_RGB_MATRIX_DIGITAL_RAIN
// #define ENABLE_RGB_MATRIX_SOLID_REACTIVE_SIMPLE
// #define ENABLE_RGB_MATRIX_SOLID_REACTIVE
// #define ENABLE_RGB_MATRIX_SOLID_REACTIVE_WIDE
// #define ENABLE_RGB_MATRIX_SOLID_REACTIVE_MULTIWIDE
// #define ENABLE_RGB_MATRIX_SOLID_REACTIVE_CROSS
// #define ENABLE_RGB_MATRIX_SOLID_REACTIVE_MULTICROSS
// #define ENABLE_RGB_MATRIX_SOLID_REACTIVE_NEXUS
// #define ENABLE_RGB_MATRIX_SOLID_REACTIVE_MULTINEXUS
// #define ENABLE_RGB_MATRIX_SPLASH
// #define ENABLE_RGB_MATRIX_MULTISPLASH
// #define ENABLE_RGB_MATRIX_SOLID_SPLASH
// #define ENABLE_RGB_MATRIX_SOLID_MULTISPLASH

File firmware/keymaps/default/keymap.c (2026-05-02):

// Copyright 2023 sporkus
// SPDX-License-Identifier: GPL-2.0-or-later

#include QMK_KEYBOARD_H
#include "../../rgb.c"

// Just something for quick testing, not meant to be used
const uint16_t PROGMEM keymaps[][MATRIX_ROWS][MATRIX_COLS] = {
    [0] = LAYOUT(
         KC_Q,   KC_W,   KC_E,   KC_R,   KC_T,             _______,  KC_Y,   KC_U,   KC_I,    KC_O,   KC_P,
         KC_A,   KC_S,   KC_D,   KC_F,   KC_G,                       KC_H,   KC_J,   KC_K,    KC_L,   KC_QUOT,
         KC_Z,   KC_X,   KC_C,   KC_V,   KC_B,                       KC_N,   KC_M,   KC_COMM, KC_DOT, KC_SLSH,
                         LT(1, KC_ESC),  KC_ENT,                     KC_SPC, LT(2, KC_BSPC)
    ),

    [1] = LAYOUT(
         _______,  _______,  _______,  _______,  _______,  QK_BOOT,  _______,  KC_7,     KC_8,     KC_9,     KC_0,
         _______,  _______,  _______,  _______,  _______,            _______,  KC_4,     KC_5,     KC_6,     _______,
         _______,  _______,  _______,  _______,  _______,            _______,  KC_1,     KC_2,     KC_3,     _______,
                                       _______,  _______,            _______,  _______
    ),

    [2] = LAYOUT(
         _______,  _______,  _______,  _______,  _______,  QK_BOOT,  _______,  _______,   _______,   _______,    _______,
         _______,  _______,  _______,  _______,  _______,            KC_LEFT,  KC_DOWN,   KC_UP,     KC_LEFT,    _______,
         _______,  _______,  _______,  _______,  _______,            _______,  _______,   _______,   _______,    _______,
                                       _______,  _______,            _______,  _______
    )
};

#ifdef ENCODER_MAP_ENABLE
const uint16_t PROGMEM encoder_map[][NUM_ENCODERS][2] = {
    [0] =   { ENCODER_CCW_CW(KC_VOLD, KC_VOLU) },
    [1] =   { ENCODER_CCW_CW(___, ___) },
    [2] =   { ENCODER_CCW_CW(___, ___) }
};
#endif

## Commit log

2023-06-25 routed pcb
    [bom.csv, designators.csv, key_matrix.kicad_sch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]
2023-06-25 more bom work
    [bom.csv, key_matrix.kicad_sch, positions.csv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]
2023-06-26 encoder debounce caps + verified CPL
    [bom.csv, designators.csv, key_matrix.kicad_sch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]
2023-06-26 silkscreen clean up
    [positions.csv]
2023-06-26 update 3d models
    [bom.csv, rgb.kicad_sch, stm32_hotswap_chiffre.kicad_sch]
2023-06-26 version freeze
    [bom.csv, positions.csv]
2023-06-27 esd and usb update/
    [bom.csv, designators.csv, positions.csv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]
2023-06-28 rerouted for better grounding
2023-06-29 cleaning up pcb
    [stm32_hotswap_chiffre.kicad_pcb, stm32_hotswap_chiffre.kicad_sch]
2023-07-13 v0.2 release
    [bom.csv, designators.csv, positions.csv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]
2023-07-13 adding front LED bypass jumper
    [key_matrix.kicad_sch, rgb.kicad_sch, stm32_hotswap_chiffre.kicad_pcb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]
2023-07-14 exporting edgecut dxf
    [stm32_hotswap_chiffre-Edge_Cuts.dxf]
2023-07-18 adding panelized plate files
    [LeChiffre_Plate.kicad_sch, LeChiffre_Plate.sch, Plate 5.14.32 PM.dxf]
2023-07-20 adding panelized plate
    [LeChiffre_Plate.sch]
2023-07-20 change center switch footprint
    [key_matrix.kicad_sch, rgb.kicad_sch, stm32_hotswap_chiffre.kicad_pcb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]
2023-07-20 add kibot documentation
    [LeChiffre_Plate-Edge_Cuts.dxf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]
2023-07-20 finishing up details
    [bom.csv, designators.csv, key_matrix.kicad_sch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]
2023-08-02 add keycap models
    [stm32_hotswap_chiffre.kicad_pcb]
2023-08-02 adding a case
    [bottom.stl, plate.stl, top.stl]
2023-08-03 add plate files
    [plate_alps.kicad_sch]
2023-09-08 add alps+mx plate
    [LeChiffre_Plate-Edge_Cuts.dxf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]
2023-09-08 alps plate should be 1.2mm
2023-09-11 smaller mousebite on plate
2023-09-15 add QR code
    [designators.csv, positions.csv, stm32_hotswap_chiffre.kicad_pcb]
2023-09-18 adding plain top stl
    [top_plain.stl]
2023-09-28 adding top case with keycap cutout
    [top_switch_cutout.stl]
2023-10-29 Chiffre RGB indicator fixes
    * Reduced default brightness
    * Uses a new config parameter `RGB_INDICATOR_BRIGHTNESS` to separate the
    control of front leds from the back leds
    * Fix the RGB indicator enable/disable code
2024-02-26 fix pin order
    [rgb.kicad_sch, stm32_hotswap_chiffre.kicad_sch]
2026-05-02 add 36 key kicad
    [key_matrix.kicad_sch, rgb.kicad_sch, stm32_chiffre_36keys.kicad_pcb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]
2026-05-02 minor touch ups
    [stm32_chiffre_36keys.kicad_pcb]
2026-05-02 fix schematic on right thumb keys
    [key_matrix.kicad_sch, rgb.kicad_sch, stm32_chiffre_36keys.kicad_pcb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]
2026-05-02 add notes
    [key_matrix.kicad_sch, rgb.kicad_sch, stm32_chiffre_36keys.kicad_pcb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]
2026-05-02 clean up
    [stm32_hotswap_chiffre-Edge_Cuts.dxf]
